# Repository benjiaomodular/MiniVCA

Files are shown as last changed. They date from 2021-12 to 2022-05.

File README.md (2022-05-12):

# MiniVCA

An LM13700 VCA based on Juanito Moore's design. Check out his original circuit here: https://drive.google.com/file/d/1J9KlYRYUHS_VxaGyPMjCsaK7Lp2Q8HFu/view

MiniVCA v1 0

# Versions

## 1.2 (Unverified)
- Changed mounting hole spacing to Doepfer standards.
- Export separate gerber files for each board instead of mousebites.

## 1.1
- Minor corrections from initial print.
- Updated front panel graphics to my new standard styles.

## 1.0
Initial design.

### Issues
- Socket for LM13700 was wrong. Used 10.16mm instead of 7.62mm width. Can be remedied by bending the IC's pins wide. Verified to work.
- No silk screen label for pots.

### Issues
- Replaced footprint for LM13700 with correct one.
- Added silk screen labels for the pots.
- Move all front panel text to F.Mask layer.

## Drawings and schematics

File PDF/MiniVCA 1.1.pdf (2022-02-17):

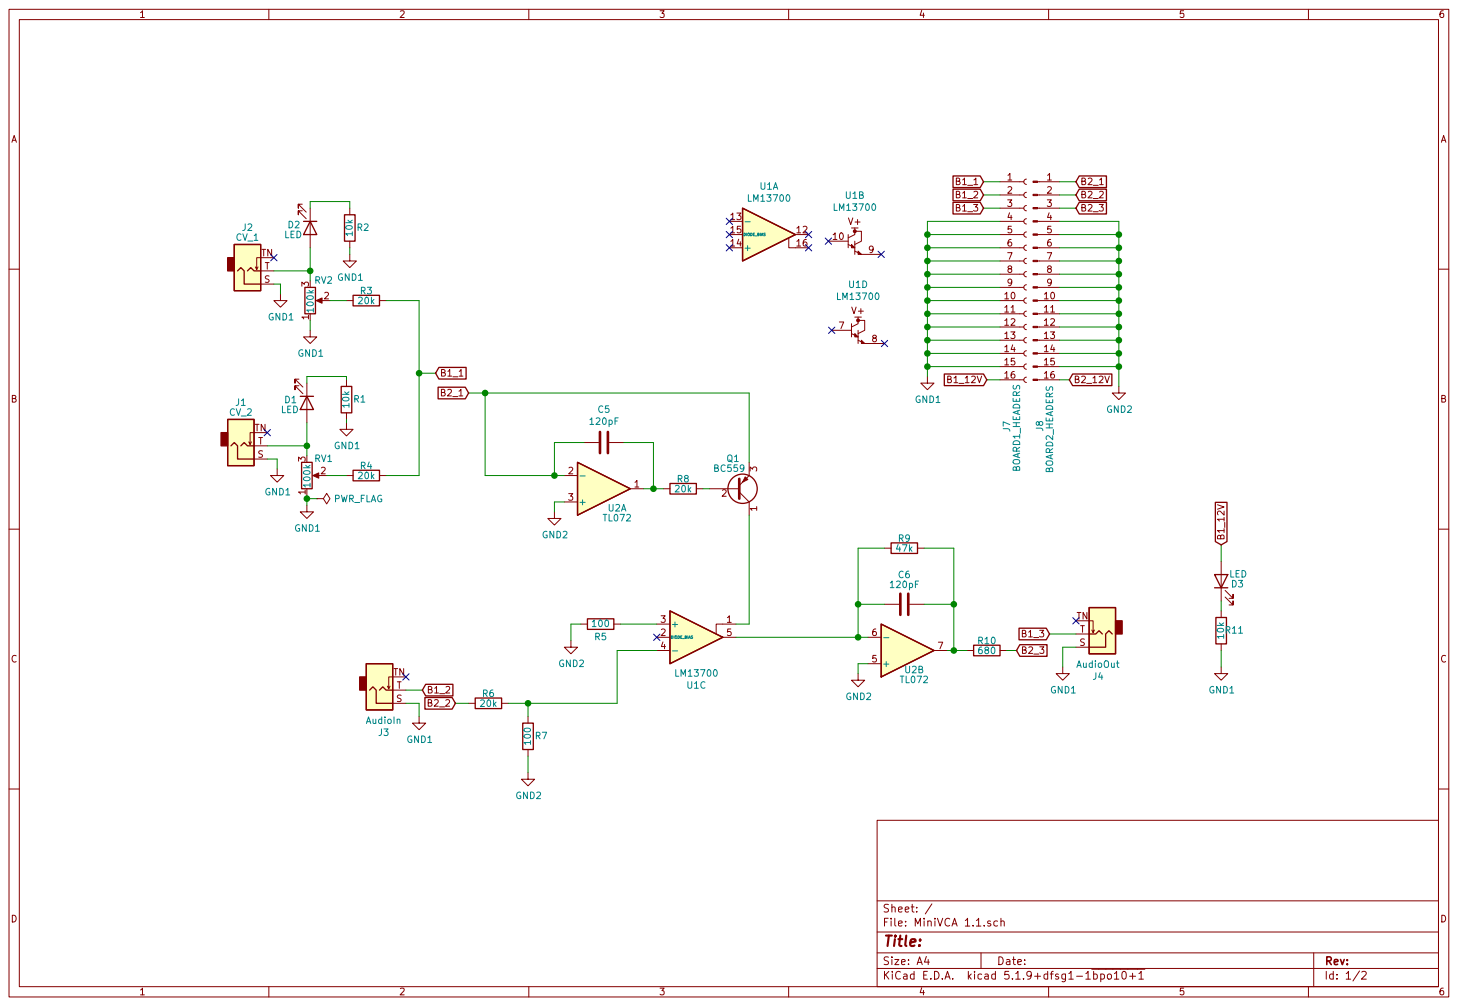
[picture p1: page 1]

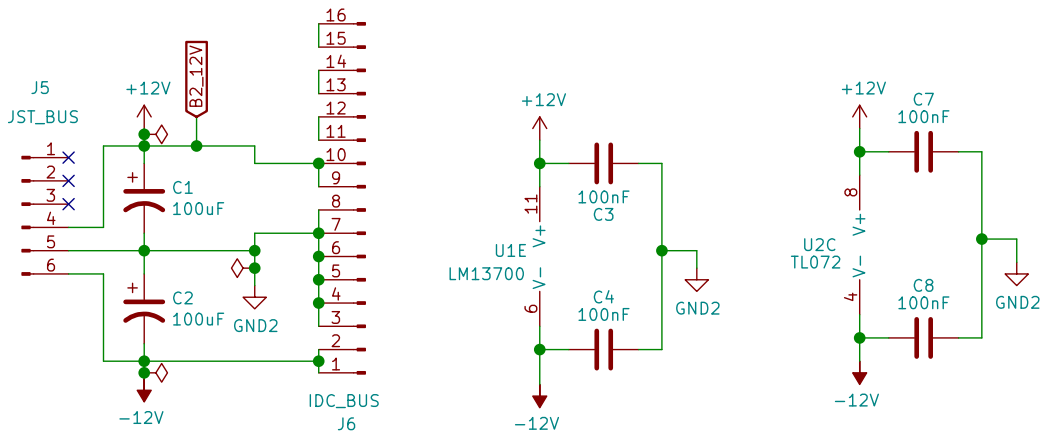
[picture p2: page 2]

Id: 2/2 Title: File: Power.sch Sheet: /Power/

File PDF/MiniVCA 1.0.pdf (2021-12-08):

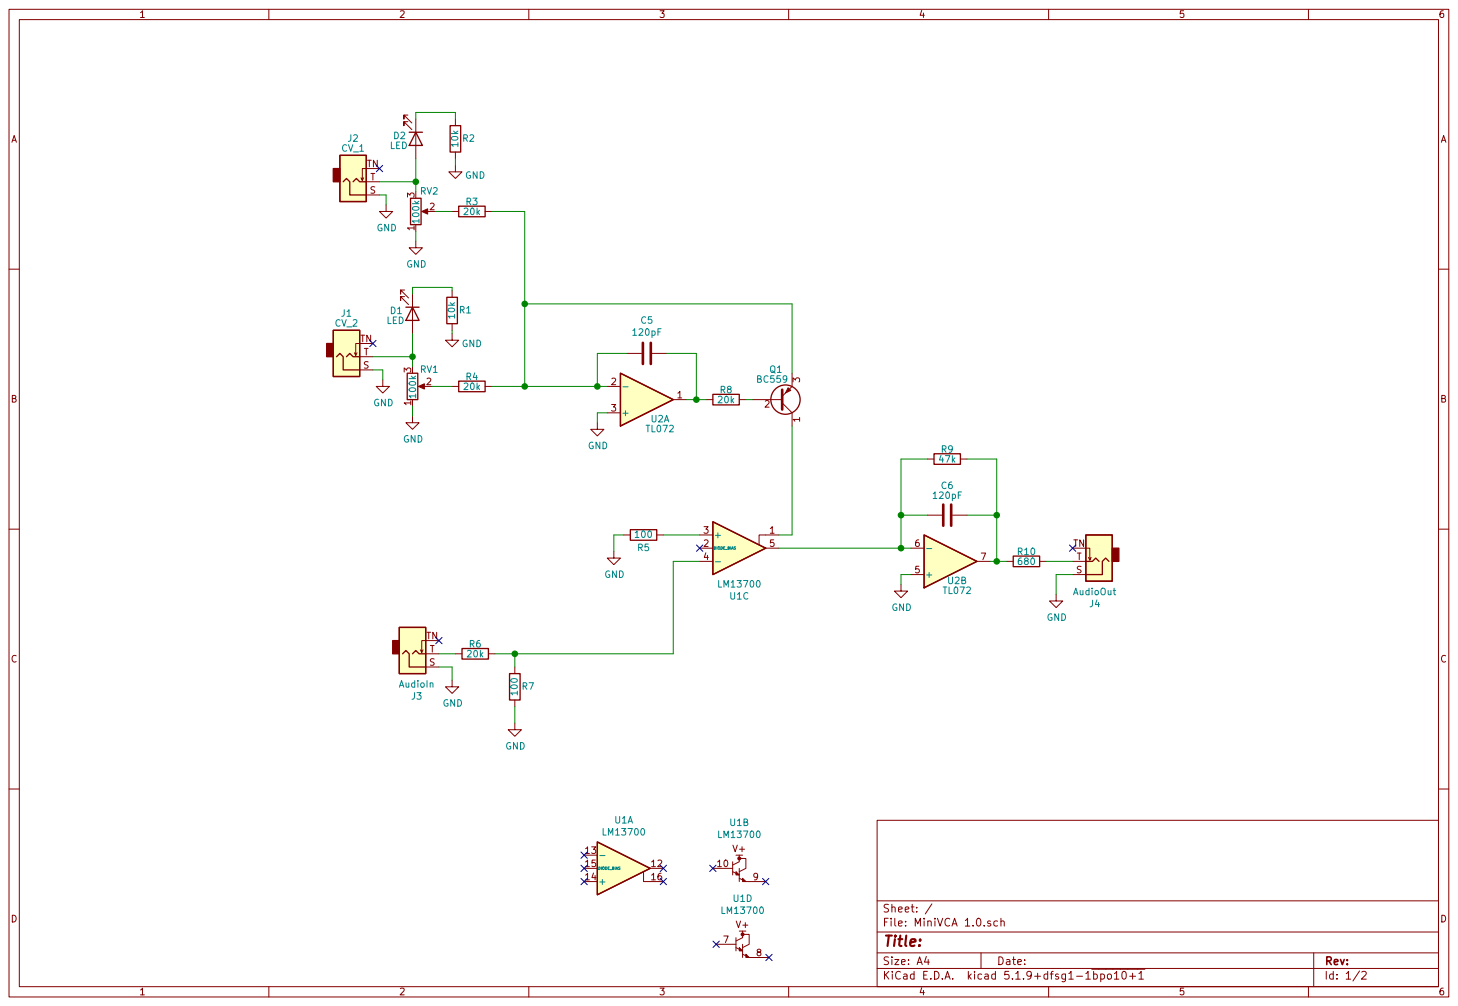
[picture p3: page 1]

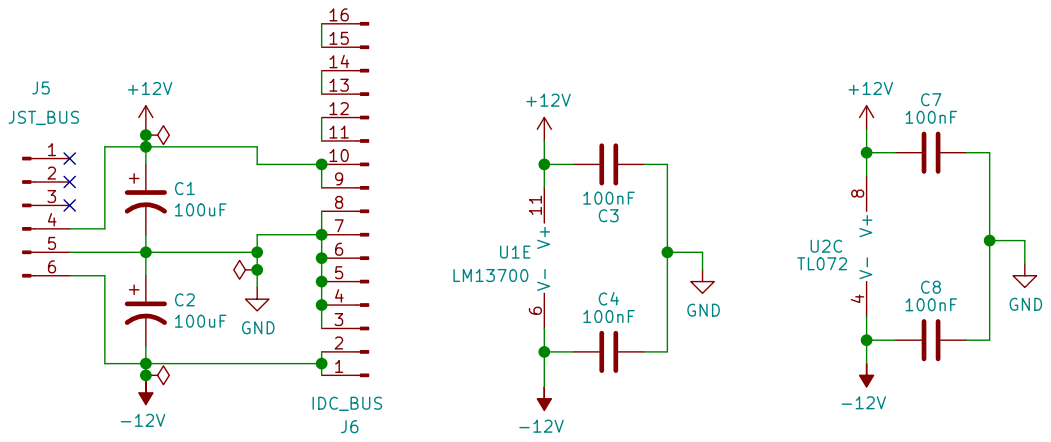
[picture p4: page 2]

Id: 2/2 Title: File: Power.sch Sheet: /Power/

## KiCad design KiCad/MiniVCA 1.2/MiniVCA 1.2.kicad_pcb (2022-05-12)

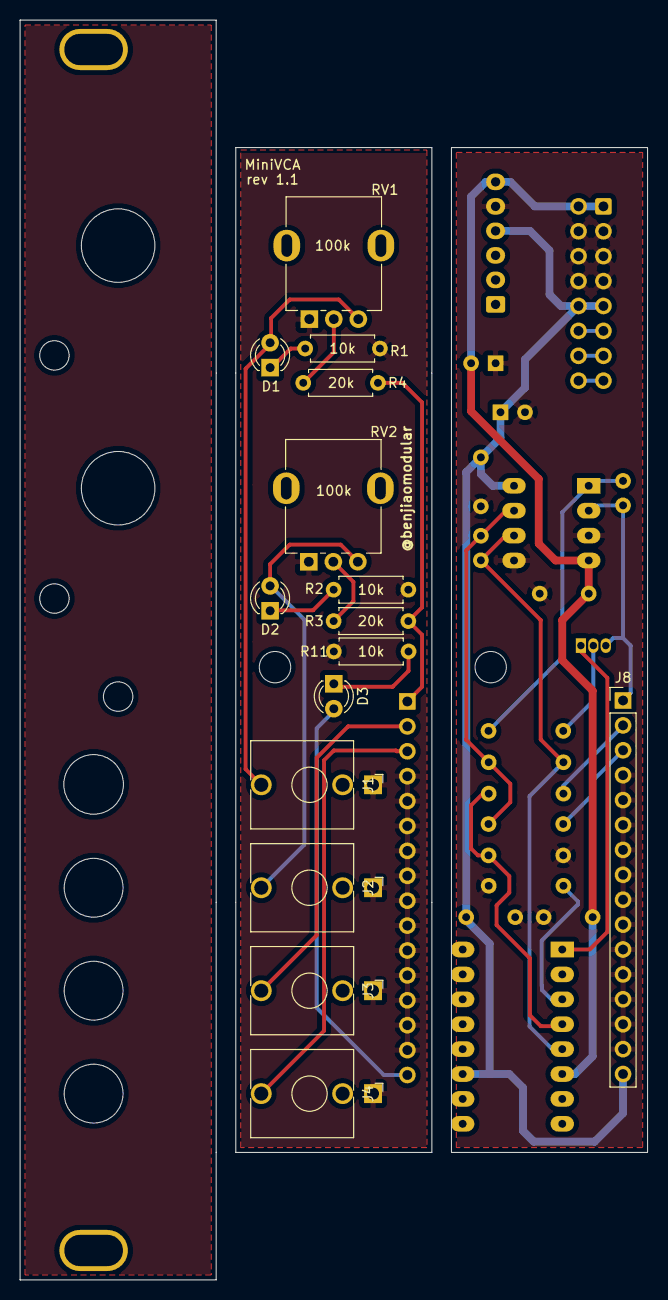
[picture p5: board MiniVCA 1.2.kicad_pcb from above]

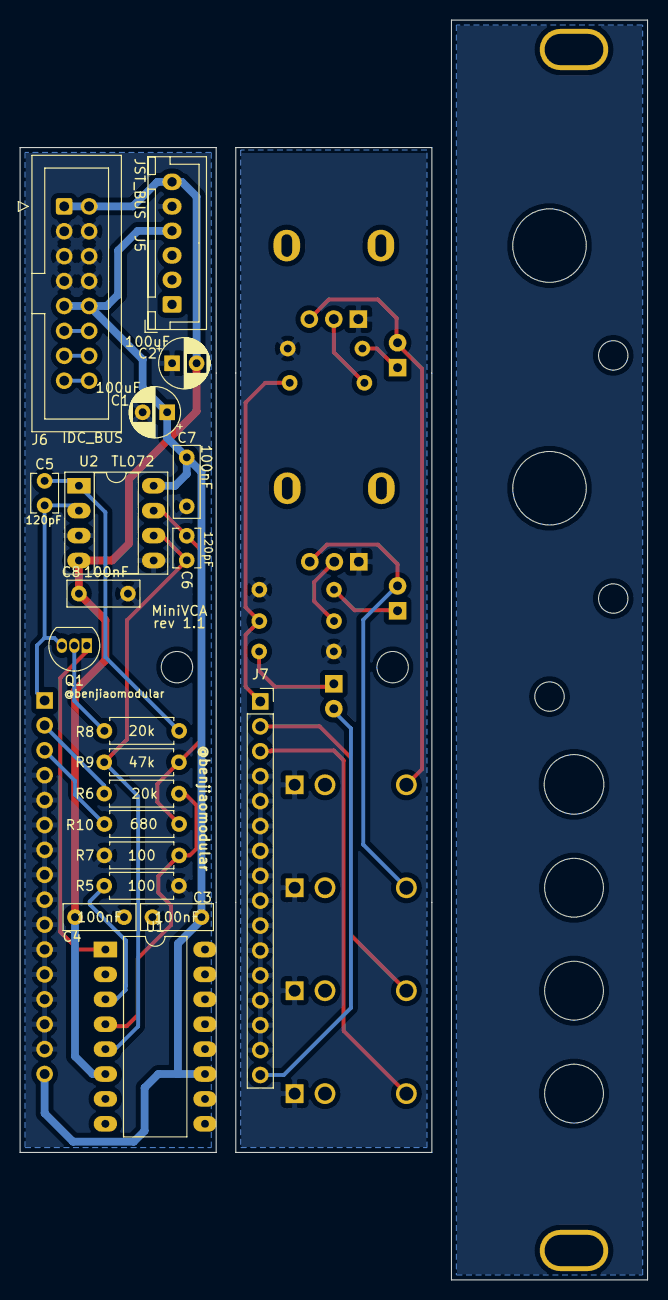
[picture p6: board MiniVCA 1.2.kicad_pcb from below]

Board: 2 copper layers, 64.0 x 128.5 mm, 35 parts (20 on the bottom side), 28 nets.

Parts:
C1, C2: 100uF; CP_Radial_D5.0mm_P2.50mm
C3, C4, C7, C8: 100nF; C_Rect_L7.2mm_W2.5mm_P5.00mm_FKS2_FKP2_MKS2_MKP2
C5, C6: 120pF; C_Disc_D3.8mm_W2.6mm_P2.50mm
D1, D2, D3: LED; LED_D3.0mm
J1: CV_2; AudioJack_3.5mm
J2: CV_1; AudioJack_3.5mm
J3: AudioIn; AudioJack_3.5mm
J4: AudioOut; AudioJack_3.5mm
J5: JST_BUS; JST_XH_B6B-XH-A_1x06_P2.50mm_Vertical
J6: IDC_BUS; IDC-Header_2x08_P2.54mm_Vertical
J7: BOARD1_HEADERS; PinSocket_1x16_P2.54mm_Vertical
J8: BOARD2_HEADERS; PinHeader_1x16_P2.54mm_Vertical
Q1: BC559; TO-92_Inline
R1, R2, R11: 10k; R_Axial_DIN0207_L6.3mm_D2.5mm_P7.62mm_Horizontal
R3, R4, R6, R8: 20k; R_Axial_DIN0207_L6.3mm_D2.5mm_P7.62mm_Horizontal
R5, R7: 100; R_Axial_DIN0207_L6.3mm_D2.5mm_P7.62mm_Horizontal
R9: 47k; R_Axial_DIN0207_L6.3mm_D2.5mm_P7.62mm_Horizontal
R10: 680; R_Axial_DIN0207_L6.3mm_D2.5mm_P7.62mm_Horizontal
RV1, RV2: 100k; Potentiometer_RV09
U1: LM13700; DIP-16_W10.16mm_LongPads
U2: TL072; DIP-8_W7.62mm_Socket_LongPads

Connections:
-12V: C2.2, C4.2, C8.2, J5.6, J6.1, J6.2, U1.6, U2.4
B1_1: J7.1, R3.1, R4.1
B1_2: J3.T, J7.2
B1_3: J4.T, J7.3
B1_12V: D3.2, J7.16
B2_1: C5.2, J8.1, Q1.3, U2.2
B2_2: J8.2, R6.2
B2_3: J8.3, R10.1
B2_12V: C1.1, C3.2, C7.2, J5.4, J6.9, J6.10, J8.16, U1.11, U2.8
GND1: J1.S, J2.S, J3.S, J4.S, J7.4, J7.5, J7.6, J7.7, J7.8, J7.9, J7.10, J7.11, J7.12, J7.13, J7.14, J7.15, R1.1, R2.1, R11.1, RV1.1, RV2.1
GND2: C1.2, C2.1, C3.1, C4.1, C7.1, C8.1, J5.5, J6.3, J6.4, J6.5, J6.6, J6.7, J6.8, J8.4, J8.5, J8.6, J8.7, J8.8, J8.9, J8.10, J8.11, J8.12, J8.13, J8.14, J8.15, R5.1, R7.1, U2.3, U2.5
unnamed: C5.1, R8.2, U2.1
unnamed: C6.1, R9.1, R10.2, U2.7
unnamed: C6.2, R9.2, U1.5, U2.6
unnamed: D1.1, R1.2
unnamed: D1.2, J1.T, RV1.3
unnamed: D2.1, R2.2
unnamed: D2.2, J2.T, RV2.3
unnamed: D3.1, R11.2
unnamed: J6.11, J6.12
unnamed: J6.13, J6.14
unnamed: J6.15, J6.16
unnamed: Q1.1, U1.1
unnamed: Q1.2, R8.1
unnamed: R3.2, RV2.2
unnamed: R4.2, RV1.2
unnamed: R5.2, U1.3
unnamed: R6.1, R7.2, U1.4

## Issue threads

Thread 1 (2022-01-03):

Use 5mm mousebites

benjiao, 2022-01-03:
JLCPCB requires 5mm wide mousebites. It'll give you a warning if you use anything shorter.

Closed 2022-05-12.

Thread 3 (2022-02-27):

Incorrect panel mount

benjiao, 2022-02-27:
Mounting holes should be 7.5mm from the left edge. Current version should still work for setups without fixed mounting holes on the rails.

Related issue: https://github.com/benjiaomodular/MiniADSR/issues/3

Closed 2022-05-12.

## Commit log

2021-12-08 Added version 1.0 schematic
    [MiniVCA 1.0.kicad_pcb, MiniVCA 1.0.sch, Power.sch]
2021-12-08 Added 4hp pcb
    [MiniVCA 1.0.kicad_pcb]
2021-12-22 Added rev1.1
    [MiniVCA 1.0-B_Cu.gbr, MiniVCA 1.0-B_Mask.gbr, MiniVCA 1.0-B_Paste.gbr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]
2021-12-27 Added files for version 1.1
    [MiniVCA 1.1-B_Cu.gbr, MiniVCA 1.1-B_Mask.gbr, MiniVCA 1.1-B_Paste.gbr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]
2022-01-17 Fixed front panel print
    [MiniVCA 1.1.kicad_pcb]
2022-02-17 Added pdf for v1.1 schematics
2022-05-12 Added v1.2
    [MiniVCA 1.2 - Control.kicad_pcb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]
